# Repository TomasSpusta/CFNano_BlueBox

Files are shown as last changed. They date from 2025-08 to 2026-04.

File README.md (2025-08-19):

# CEITEC Nano Core Facility BlueBox

luebox_reneder_v3

BlueBoxes are an extension for the core facility Ceitec Nano booking/ reservation system (https://today.ceitec.cz/nano and https://booking.ceitec.cz/) created with the intention of easing the reservation process and increasing the effectiveness of instrument usage in the core facility. 

The basic usage idea of creating the BlueBoxes is to authorise previously created reservations by swiping the user's card (RFID) over the RFID reader inside the BlueBox. The authorisation process is then initiated, checking user credentials and the presence of a reservation linked with the user and equipment. If authorisation is successful, the initial time of the reservation is edited to correspond to real time. If the user does not authorise the reservation, it is cancelled after a timeout, providing a free slot for another user. Additional features are: the ability to stop a reservation from the BlueBox if needed, and the ability to extend the running reservation on the spot from the BlueBox.

BlueBoxes are designed to be relatively minimalistic, cheap, yet functional devices operating on the Raspberry Pi 4, with an LCD display and an RFID reader.

RPi4 was selected because it provides LAN/Ethernet and WIFI connectivity, the Python language is relatively easy to program, and there are numerous existing libraries for peripheral modules and RPi4. Used modules (RFID reader, LCD display, buttons) are widely available.

The [electronic](../../wiki/Hardware) side of the BlueBoxes is composed of modules. Due to still running development (discovering required functions), the modularity and swapability of modules were prioritised over the possible compact size of the custom PCB (maybe in the future). 

BlueBox case is 3D [printed](../../wiki/Printing) from PLA filament.

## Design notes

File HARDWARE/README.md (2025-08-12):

# Bill of parts and materials:

1. 3D printed parts:
    - RPi-plane
    - LCD-plane
    - RFID-plane (2x button holders)
    - Back-plane (1x button holder)
    - SDCard-plane
    - USB-plane
    - Connection-plane

2. Fasteners
    - 3x8 mm screw to thermoplastic (total 14)
      - 4x LCD-plane
      - 4x RPi-plane
      - 2x Back-plane
      - 4x RFID-plane
    - 10x Threaded insert M3x4mm
    - 10x M3x35 bolt

3. Electro modules/parts
    -  1x Raspberry Pi 4
    -  1x RPi power supply (USB-C, 5V, 3A)
    -  1x Heatsing for RPi CPU
    -  1x MFRC522 RFID module
    -  1x 2004 LCD with I2C module
    -  3x 12x12 mm push button
    -  1x button cap red
    -  1x button cap green
    -  1x button cap blue
    -  17x dupont connector wires (7 RFID, 4 LCD, 6 buttons)
    -  1x 20x2 dupont female coonector (RPi board)
    -  1x 8x1 dupont female connector (RFDI module)
    -  1x 4x1 dupont female connector (LCD module)
    -  1x 3x1 duppont header (to be soldered on RPi)

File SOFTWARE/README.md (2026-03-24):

# Bluebox Software

Async Python control software for a hardware reservation terminal:
- reads RFID cards
- controls a 20x4 I2C LCD
- handles GPIO buttons for stop/extend actions
- calls backend APIs for user/reservation flow
- writes operational logs to Google Sheets

## Overview

Main execution starts in `main.py` and runs an async state machine from `states/`.

State flow:
1. `InitState`
2. `WaitingForCardState`
3. `VerifyUserState`
4. `VerifyReservationState`
5. `InReservationState`
6. `UserStopReservationState` or `ExtendReservationState` or `TimeOutState`
7. Back to `WaitingForCardState`

## Repository Structure

- `main.py`: app bootstrap and dependency wiring
- `app_context.py`: shared runtime context passed between states
- `states/`: state machine implementation
- `api_client.py`: backend API integration
- `networking.py`: connectivity checks + safe API wrapper
- `token_handler.py`: token persistence/refresh logic
- `rfid_reader.py`: MFRC522 card reader abstraction
- `lcd_display.py`: LCD adapter
- `screen_manager.py`: LCD screen text templates
- `button_watcher.py`: GPIO button hold detection
- `logger.py`: Google Sheets logging
- `model_classes.py`: domain data models
- `requirements.txt`: Python dependencies
- `improvements.md`: architecture improvement roadmap

## Requirements

Hardware/runtime expectations:
- Raspberry Pi (or compatible Linux SBC)
- MFRC522 RFID reader
- 20x4 I2C LCD with PCF8574 backpack
- 2 GPIO buttons (stop/extend)
- Internet connection for backend + Google Sheets logging

Software:
- Python 3.11+ recommended
- System access to GPIO, I2C, SPI as required by your OS image

## Installation

```bash
python3 -m venv .venv
source .venv/bin/activate
pip install -r requirements.txt
```

## Configuration

`config/*` is ignored in git. Create local config files manually.

Create `config/config.py` with an exported object named `config` containing at least:

```python
from pathlib import Path

class Config:
    # API
    API_KEY = "<your-api-key>"
    FETCH_TOKEN = "https://.../token"
    EQUIPMENT_BY_MAC = "https://.../equipment/by-mac"
    CONTACT_BY_RFID = "https://.../contact/by-rfid"
    RECORDING_START = "https://.../recording/start"
    RECORDING_INFO = "https://.../recording/{reservation_id}"
    RECORDING_STOP = "https://.../recording/stop"

    # Token persistence
    TOKEN_FILE = Path("/home/bluebox/token.json")

    # Google logger
    LOGGER_JSON = "/home/bluebox/service-account.json"
    LOGGER_ACC = "logs-owner@example.com"

config = Config()
```

Notes:
- `LOGGER_JSON` must point to a valid Google service-account JSON file.
- Ensure file permissions are restricted for secrets and token files.
- If paths differ on your device, update values accordingly.

## GPIO Pin Mapping

Current defaults in `main.py`:
- Stop button: GPIO `21`
- Extend button: GPIO `13`

If your wiring differs, update button pin numbers in `main.py`.

## Running

```bash
python main.py
```

The process:
- initializes screen + RFID + API client
- starts background network monitor
- enters infinite async state loop

## Logging

- Primary logs: Google Sheets (`logger.py`)
- Fallback local log: `/home/bluebox/log_local.txt`

If Google logging fails, check:
- service account file path
- sharing permissions for `LOGGER_ACC`
- internet connectivity

## Troubleshooting

### App stuck on offline screen
- Verify internet on device (`ping 1.1.1.1`)
- Verify DNS/network routing
- Check API endpoint availability

### RFID cards not detected
- Verify MFRC522 wiring and SPI enabled
- Confirm process has required permissions
- Check reader cooldown behavior in `rfid_reader.py`

### Buttons do not trigger actions
- Verify GPIO pin wiring and pull-up/pull-down setup
- Confirm hold duration behavior in `button_watcher.py`
- Ensure app is in `InReservationState` (buttons are monitored there)

### LCD does not display
- Verify I2C enabled and address (`0x27` by default)
- Run `i2cdetect` to confirm device visibility
- Confirm LCD dimensions and compatibility with `RPLCD`

## Development Notes

- The codebase is async-first; avoid introducing blocking I/O in state logic.
- Prefer one module for button watching (`button_watcher.py`) to avoid duplication with `button_handler.py`.
- See `improvements.md` for prioritized architecture refactor plan.

## Safety

Do not commit:
- API keys
- token files
- Google service-account credentials
- device-specific local config

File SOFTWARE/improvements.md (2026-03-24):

# Software Architecture Improvement Plan

This document proposes a practical, phased improvement roadmap for the current Python async state-machine app (RFID + GPIO buttons + LCD + HTTP API + Google Sheets logging).

## 1. Current-State Assessment

### Strengths
- Clear high-level flow with explicit states (`Init -> WaitingForCard -> VerifyUser -> VerifyReservation -> InReservation -> End`).
- Hardware integrations are encapsulated in dedicated modules (`rfid_reader.py`, `lcd_display.py`, button watcher).
- Use of `asyncio` enables non-blocking orchestration at architecture level.
- Domain models are small and easy to understand.

### Key Risks and Gaps
- Reliability risk: several runtime bugs and fragile error paths.
- Concurrency risk: blocking hardware I/O inside async flow.
- Maintainability risk: duplicated API/network/token logic and inconsistent patterns.
- Observability risk: `print()`-based logging with partial fallback.
- Quality risk: missing test suite and no CI gates.
- Operational risk: no graceful shutdown / lifecycle management.

## 2. Immediate Critical Fixes (Phase 0 - 1 to 2 days)

1. Fix hard runtime bugs.
- `logger.py`: `Path.write_text(..., append=True)` is invalid; replace with explicit append mode (`open('a')`) in a thread-safe helper.
- `states/offline_state.py`: references `context.api.check_connection()` which does not exist; either remove state or add a valid connectivity API.
- `model_classes.py`: `Reservation.warning_sent`, `ended_by_user`, `ended_by_time` are class attributes; convert to dataclass instance fields.
- `app_context.py`: `button_lock = asyncio.Lock()` at class definition time can bind to wrong event loop; move to instance initialization.

2. Prevent event-loop blocking.
- `rfid_reader.py`: wrap blocking `self.reader.read()` using `asyncio.to_thread`.
- Verify all hardware calls touching GPIO/LCD are either async-safe or wrapped.

3. Add defensive API timeout defaults.
- Define centralized aiohttp timeout config (connect/read/total).
- Apply request-level timeout and consistent exception handling.

4. Remove dead/duplicate module behavior.
- `button_handler.py` and `button_watcher.py` overlap; keep one implementation and delete/retire the other.

Acceptance criteria:
- App runs for >2h without deadlock.
- No `AttributeError` / loop-binding errors in logs.
- Card scanning remains responsive while network checks happen.

## 3. Foundation Refactor (Phase 1 - 3 to 5 days)

1. Introduce layered architecture.
- `domain/`: entities and pure business rules.
- `application/`: state machine orchestration/use-cases.
- `infrastructure/`: GPIO/LCD/RFID/API/Google Sheets adapters.
- `interfaces/` (optional): CLI/bootstrap/runtime wiring.

2. Normalize state transitions.
- Define explicit transition map and terminal fallback behavior.
- Standardize state contract: input context, returned next state, and error behavior.

3. Centralize configuration.
- Replace implicit `from config import config` coupling with typed settings object.
- Support env-based config with validation (e.g., `pydantic-settings` or dataclass + validation).
- Keep secrets out of repository and document required variables.

4. Unify API client behavior.
- Reuse one shared `aiohttp.ClientSession` per app lifecycle.
- Add typed API responses and normalized error objects.
- Deduplicate token fetch flow (`APIClient.fetch_token` vs `networking.fetch_token`).

Acceptance criteria:
- Single dependency direction (state logic does not import hardware modules directly).
- One token-refresh implementation.
- Config validation fails fast on startup with clear message.

## 4. Reliability and Resilience (Phase 2 - 3 to 4 days)

1. Build robust online/offline strategy.
- Create a `ConnectivityService` with backoff and jitter.
- Separate connectivity state from UI rendering side effects.
- Avoid two independent offline loops (`network_monitor` + `wait_until_online`) racing screen output.

2. Introduce operation policies.
- Retry policy for transient HTTP failures (idempotent calls only).
- Circuit breaker for persistent backend failures.
- Graceful degradation mode (local queue of critical events while offline).

3. Improve shutdown/startup lifecycle.
- Add structured startup sequence and health checks.
- Handle SIGTERM/SIGINT: cancel tasks, cleanup GPIO/LCD, flush pending logs.

Acceptance criteria:
- Controlled behavior during network flap tests.
- Clean shutdown without hung tasks or orphan GPIO handlers.

## 5. Observability and Logging (Phase 3 - 2 to 3 days)

1. Replace `print()` with structured logging.
- Use Python `logging` (JSON format preferred).
- Include correlation fields: `state`, `card_id` hash, `reservation_id`, `request_id`.

2. Improve logger subsystem.
- Decouple business events from Google Sheets writer via queue.
- Non-blocking buffered writes with retry and fallback file sink.
- Add clear log event schema versioning.

3. Add metrics.
- Track: API latency, API error counts by endpoint, state transition counts, RFID read latency, button events.

Acceptance criteria:
- Operational timeline can be reconstructed from logs.
- Failures are diagnosable without reproducing locally.

## 6. Security Hardening (Phase 4 - 1 to 2 days)

1. Secret handling.
- Store API keys/service-account path via environment or secret manager.
- Ensure token file permissions are restrictive.

2. Data handling.
- Avoid logging sensitive user fields directly (`full_name`, raw token).
- Add minimal PII policy in docs.

3. Dependency and supply-chain checks.
- Add vulnerability scanning in CI (`pip-audit` or equivalent).
- Pin and regularly update dependencies.

Acceptance criteria:
- No credentials in code/config files.
- Basic security checklist passes in CI.

## 7. Test Strategy and Quality Gates (Phase 5 - 4 to 6 days)

1. Unit tests.
- `token_handler` expiration logic.
- state transitions for success/failure/offline paths.
- reservation warnings and extension boundary conditions.

2. Integration tests.
- Mock API with `aioresponses`.
- Simulate RFID/button inputs with adapter fakes.

3. Hardware-in-the-loop smoke tests.
- Minimal scripted checks for LCD write, RFID read, button press events.

4. CI pipeline.
- `ruff` + `black` + `mypy` + `pytest` as required checks.

Acceptance criteria:
- >70% coverage on core state/application modules.
- PRs blocked when lint/types/tests fail.

## 8. Developer Experience and Documentation (Phase 6 - 1 to 2 days)

1. Add missing docs.
- `README.md`: architecture, setup, run commands, env vars.
- `docs/architecture.md`: component diagram and state transition diagram.
- `docs/operations.md`: deployment, restart, troubleshooting, logs.

2. Standardize project tooling.
- Add `pyproject.toml` and tool configs.
- Add `Makefile`/task runner for local commands (`lint`, `test`, `run`).

3. Track architectural decisions.
- Add ADRs for major choices (state machine model, logging backend, retry policy).

Acceptance criteria:
- New engineer can run and debug app within 30 minutes.

## 9. Proposed Execution Order

1. Phase 0: critical bug and blocking-I/O fixes.
2. Phase 1: architecture/config/API consolidation.
3. Phase 2: resilience and lifecycle controls.
4. Phase 3: observability uplift.
5. Phase 4: security hardening.
6. Phase 5: tests + CI quality gates.
7. Phase 6: docs and DX completion.

## 10. Backlog of Specific Code-Level Changes

- [ ] Fix fallback local logger append implementation in `logger.py`.
- [ ] Convert `Token` to dataclass and `Reservation` flags to instance fields.
- [ ] Move `button_lock` to per-context initialization.
- [ ] Replace blocking RFID read with threaded call.
- [ ] Create shared `ClientSession` lifecycle in `main.py` and inject into `APIClient`.
- [ ] Remove duplicate `fetch_token` implementation and consolidate in one service.
- [ ] Replace `print` with structured logger.
- [ ] Add startup config validator.
- [ ] Add graceful shutdown hooks and task cancellation handling.
- [ ] Add first wave of unit tests for token + state transitions.

## 11. Notes/Assumptions

- The `config/` directory is gitignored, so this plan assumes runtime config exists outside repository.
- Hardware dependencies (GPIO/LCD/RFID) require interface abstraction for full CI testability.
- Google Sheets logging can remain, but should be isolated from synchronous app flow.

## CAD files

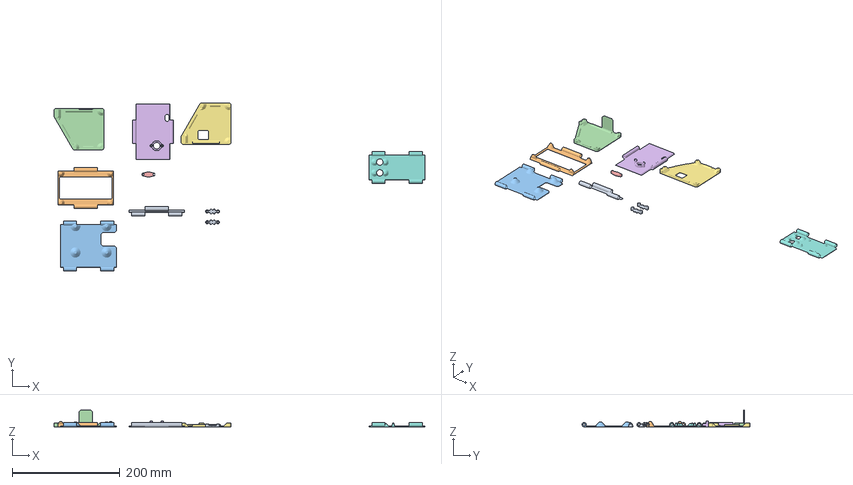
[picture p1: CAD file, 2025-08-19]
HARDWARE/bluebox_v5_print XL.3mf
690.2 x 312.5 x 31.0 mm
Conection-plane v24
LCD-plane v37
RPI-plane v36
SDCard-side_plane v68
back side button holder
Merged
USB-side_plane v22
RFID-plane v80 x 2

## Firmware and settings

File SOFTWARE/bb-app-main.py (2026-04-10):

import asyncio
import contextlib
import signal
import aiohttp
from states.init_state import InitState
from app_context import AppContext
from screen_manager import Screens
from lcd_display import LCDController
from rfid_reader import RFIDReader
from api_client import APIClient
from gpiozero import Button
from networking import network_monitor
from http_config import REQUEST_TIMEOUT


async def main():
    stop_event = asyncio.Event()
    loop = asyncio.get_running_loop()

    for sig in (signal.SIGINT, signal.SIGTERM):
        with contextlib.suppress(NotImplementedError):
            loop.add_signal_handler(sig, stop_event.set)

    context = AppContext()  # Shared app context passed to all states
    context.state = InitState()  # Start in InitState (loads config, token, etc.)
    context.screens = Screens(
        LCDController()
    )  # LCD controller wrapped by screen manager

    # Define GPIO buttons with pin numbers and debounce/hold times
    context.stop_btn = Button(21, hold_time=0.1, bounce_time=0.05)
    context.extend_btn = Button(13, hold_time=0.1, bounce_time=0.05)
    context.rfid_reader = RFIDReader()  # RFID input (hardware abstraction)

    # Global async lock for shared state (e.g. logging)
    context.lock = asyncio.Lock()

    network_task = None
    try:
        async with aiohttp.ClientSession(timeout=REQUEST_TIMEOUT) as session:
            context.api = APIClient(session=session)  # API handler (auth, user, reservation)

            # Start network monitor as background task (e.g. to update UI or trigger OfflineState)
            network_task = asyncio.create_task(network_monitor(context.screens, context))

            # Main control loop: executes and transitions between states
            while not stop_event.is_set():
                state_task = asyncio.create_task(context.state.run(context))
                stop_task = asyncio.create_task(stop_event.wait())

                done, pending = await asyncio.wait(
                    [state_task, stop_task],
                    return_when=asyncio.FIRST_COMPLETED,
                )

                for task in pending:
                    task.cancel()
                    with contextlib.suppress(asyncio.CancelledError):
                        await task

                if stop_task in done:
                    state_task.cancel()
                    with contextlib.suppress(asyncio.CancelledError):
                        await state_task
                    break

                context.state = state_task.result()
    finally:
        if network_task is not None:
            network_task.cancel()
            with contextlib.suppress(asyncio.CancelledError):
                await network_task

        if context.stop_btn is not None:
            context.stop_btn.close()
        if context.extend_btn is not None:
            context.extend_btn.close()


if __name__ == "__main__":
    asyncio.run(main())

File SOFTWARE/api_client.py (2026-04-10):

from typing import Optional
from model_classes import User, Instrument, Reservation, Token
from config import config
import unidecode
import aiohttp
import asyncio
from http_config import REQUEST_TIMEOUT


class APIClient:
    def __init__(self, session: aiohttp.ClientSession):
        self.session = session

    # Fetch instrument data based on MAC address (and store IP info locally)
    async def fetch_instrument_data(self, mac: str, ip: str) -> Optional[Instrument]:
        print("Instrument data: Fetching...")
        url = config.EQUIPMENT_BY_MAC

        try:
            # Send POST request to fetch instrument info using MAC
            async with self.session.post(
                url, json={"mac_address": mac}, timeout=REQUEST_TIMEOUT
            ) as response:
                if response.status != 200:
                    print(f"Response status {response.status}")
                    error_content = await response.json()
                    print(f"Error content {error_content}")
                    error_message = error_content.get("message")
                    print(f"Message: {error_message}")
                    return None

                response_json = await response.json()

                if not response_json:
                    return None

                # Parse and return Instrument object
                instrument = Instrument(
                    id=response_json[0]["equipmentid"],
                    name=response_json[0]["alias"],
                    mac_address=mac,
                    ip=ip,
                )
                print("Instrument data: Fetched.")
                return instrument

        except (aiohttp.ClientError, asyncio.TimeoutError):
            print("Error in fetch instrument")
            return None

    # Retrieve authentication token from API using API key
    async def fetch_token(self) -> Optional[Token]:
        api_key = config.API_KEY
        url = config.FETCH_TOKEN

        try:
            print("Token API call")
            async with self.session.post(
                url, json={"apiKey": api_key}, timeout=REQUEST_TIMEOUT
            ) as response:
                if response.status != 200:
                    print(f"Response status {response.status}")
                    error_content = await response.json()
                    print(f"Error content {error_content}")
                    error_message = error_content.get("message")
                    print(f"Message: {error_message}")
                    return None

                response_json = await response.json()

                if not response_json:
                    print("Empty response from api")
                    return None

                # Create and return Token object
                token = Token(
                    string=response_json["accessToken"],
                    expiration=response_json["expiresAt"],
                )
                return token

        except (aiohttp.ClientError, asyncio.TimeoutError):
            print("Error in fetch_token")
            return None

    # Fetch user data based on RFID card ID
    async def fetch_user_data(self, card_id) -> Optional[User]:
        print("User data: Fetching...")
        url = config.CONTACT_BY_RFID

        try:
            # POST request to fetch user info by RFID
            async with self.session.post(
                url, json={"rfid": card_id}, timeout=REQUEST_TIMEOUT
            ) as response:
                if response.status != 200:
                    print(f"Response status {response.status}")
                    error_content = await response.json()
                    print(f"Error content {error_content}")
                    error_message = error_content.get("message")
                    print(f"Message: {error_message}")
                    return None

                response_json = await response.json()
                # print(f"Response from user: {response_json}")

                if not response_json:
                    print("Empty response from api")
                    return None

                # Normalize name (e.g., remove diacritics)
                name = response_json[0]["firstname"]
                full_name = response_json[0]["full_name"]
                name_non_dia = unidecode.unidecode(name)

                # Create and return User object
                user = User(
                    id=response_json[0]["contactid"],
                    name=name_non_dia,
                    card_id=card_id,
                    full_name=full_name,
                )
            print("User data: Fetched.")
            return user

        except (aiohttp.ClientError, asyncio.TimeoutError):
            print("Error in fetch user")
            return None

    # Start or extend a reservation
    async def start_extend_reservation(
        self, user: User, instrument: Instrument, token: Token
    ) -> Optional[Reservation]:
        print("Recording START/EXTEND: API Call...")
        payload = {"contactId": user.id, "equipmentId": instrument.id}
        headers = {"Authorization": "Bearer " + token.string}
        url = config.RECORDING_START
        try:
            async with self.session.post(
                url=url, json=payload, headers=headers, timeout=REQUEST_TIMEOUT
            ) as response:
                if response.status != 200:
                    error_content = await response.json()
                    error_message = error_content.get("status")
                    print(f"Message: {error_message}")
                    return None
                else:
                    response_content = await response.json()

                    session = Reservation(
                        recording_id=response_content["recording"],
                        reservation_id=response_content["reservation"],
                        remaining_time=int(response_content["timetoend"]),
                    )
                    print("Recording START/EXTEND: Started/Extended.")
                    print(f"Message: {response_content}")
                    return session

        except (aiohttp.ClientError, asyncio.TimeoutError):
            print("Error in start_recording")
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

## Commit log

2025-08-12 Rename BOM.md to Bill of materials and parts.md
2025-08-12 Update Bill of materials and parts.md
2025-08-13 Rename Bill of materials and parts.md to README.md
2026-04-10 Add SSH-key based deployment scripts and sparse checkout support
    [devices.csv]
